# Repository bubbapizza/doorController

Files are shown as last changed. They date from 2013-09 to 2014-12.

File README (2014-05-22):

This is (going to be) a full DIY solution for a door controller.
The door can be locked or unlocked using an arduino or a raspberry pi
to interface witha Parallax serial RFID card reader for the controller
hardware.

The backend logic for the door controller is handled in python.  
The arduino sketches have no logic in them whatsoever.  All they do is 
accept single character commands over the virtual serial port 
and control some lights, a buzzer and rfid controller.  All back-end logic
is handled using python.

I've also included a couple Arduino sketches for dealing w/ Wiegand RFID 
card readers.  I'm not sure if the wiegand stuff actually works or not
since I never tested it.  One sketch is an RFID emulator which is 
supposed to emulate a wiegand card reader.  The other sketch is for 
controlling a door using a device that speaks the wiegand protocol.
testing

Shawn Wilson
Oct 29, 2013

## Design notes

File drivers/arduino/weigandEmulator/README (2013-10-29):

This sketch is for emulating a Wiegand RFID reader.  Upload this
sketch to an arduino, then you can type in RFID codes over the
serial port and it will send out the codes on pins 8 & 9 using the
Wiegand protocol.

NOTE: this has not been tested at all.  It may not work.

Shawn Wilson
Sept 11, 2013

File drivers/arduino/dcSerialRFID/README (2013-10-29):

This is an arduino sketch that acts as a simple door controller.
It reads RFID cards from a Parallax serial RFID card reader.  It also
controls two LEDs, a piezo buzzer and a relay to open the door.  

The controller has no logic in it whatsoever.  All it does is accept 
single character commands over the serial port which can be used
to control the lights, buzzers and rfid controller.  All logic should
be handled by external software.

Shawn Wilson
Sept. 13, 2013

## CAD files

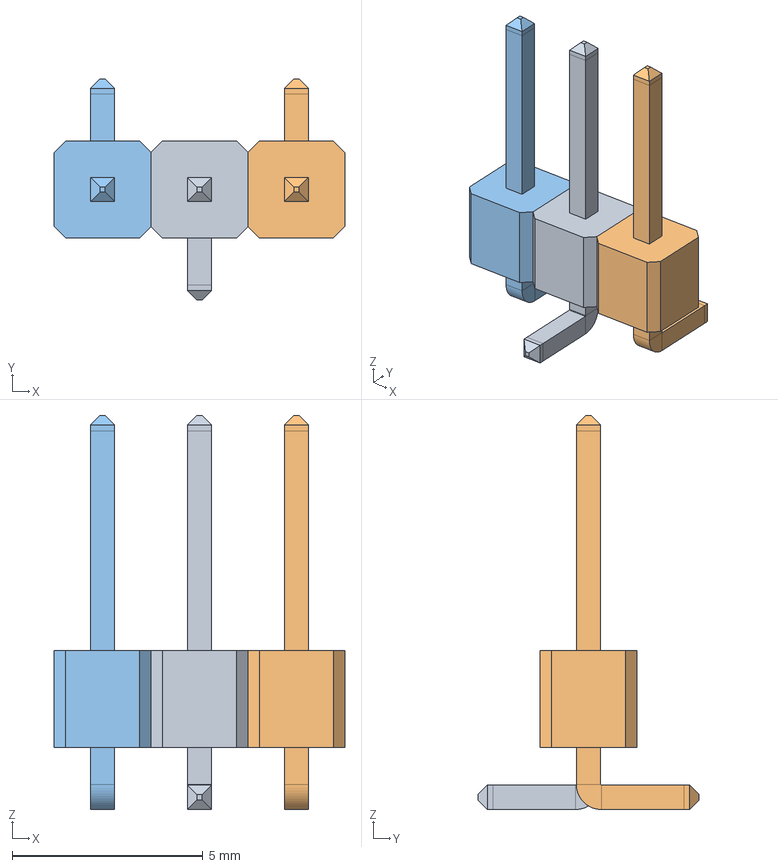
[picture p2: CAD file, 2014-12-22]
KiCAD/rpi-door-control/3D_models/SMD_Pins_x3.FCStd
7.62 x 5.80 x 10.3 mm
SMD Pin
SMD Pin (Mirror #1)
SMD Pin (Mirror #2)

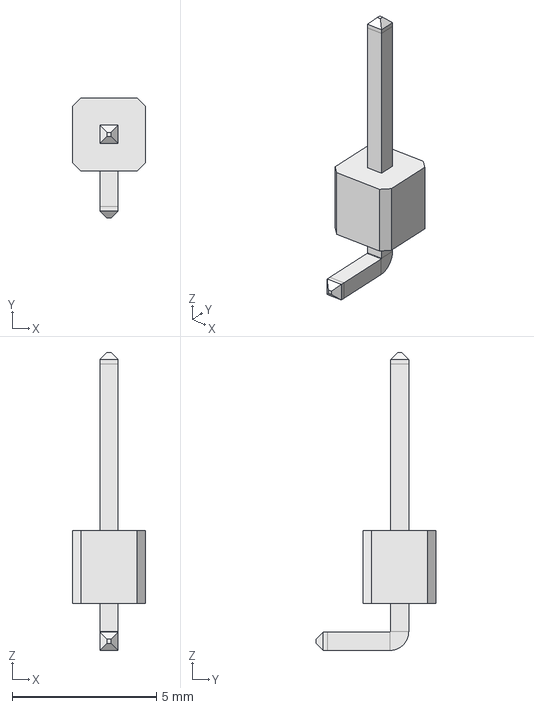
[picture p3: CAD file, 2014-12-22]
KiCAD/rpi-door-control/3D_models/SMD_Pin.FCStd
2.54 x 4.17 x 10.3 mm

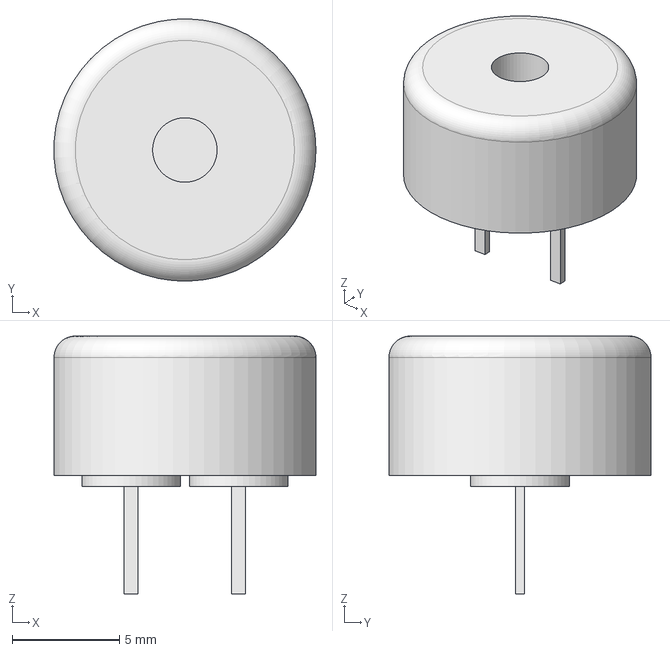
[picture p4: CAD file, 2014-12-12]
KiCAD/rpi-door-control/3D_models/TDK_buzzer.FCStd
12.2 x 12.2 x 12.0 mm

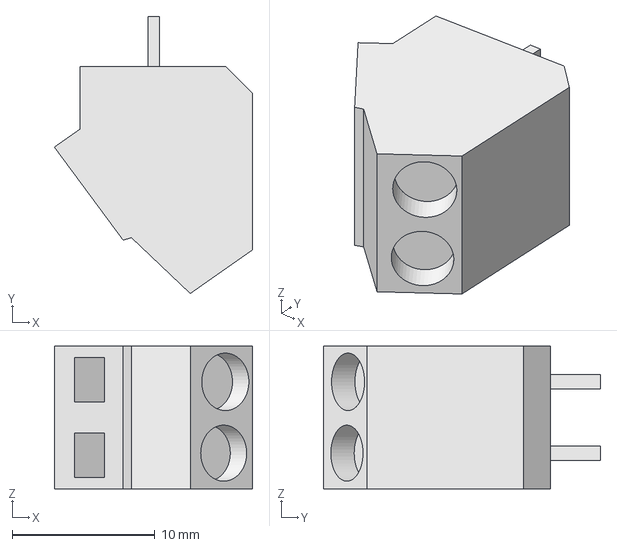
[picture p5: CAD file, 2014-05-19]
KiCAD/rpi-door-control/3D_models/kf103.FCStd
13.9 x 19.4 x 10.0 mm

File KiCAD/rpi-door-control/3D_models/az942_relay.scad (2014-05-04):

module pin134() {
	cube(size=[0.3, 1.0, 3.5], center=true);
};

module pin25() {
	cube(size=[0.3, 0.9, 3.5], center=true);
};

cube(size=[16.5, 22.5, 16.8]);
translate([(16.5 / 2), 2.1, (-3.5 / 2)]) rotate([0, 0, 90]) pin134();
translate([(16.5 / 2 - 6), 16.3, (-3.5 / 2)]) pin134();
translate([(16.5 / 2 + 6), 16.3, (-3.5 / 2)]) pin134();
translate([(16.5 / 2 + 6), 4.1, (-3.5 / 2)]) pin25();
translate([(16.5 / 2 - 6), 4.1, (-3.5 / 2)]) pin25();

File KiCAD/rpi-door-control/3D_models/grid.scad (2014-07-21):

/* This module creates grids. */

module grid(
   gridX, 
   gridY, 
   borderX, 
   borderY, 
   meshSolid,    // width of solid part of grid
   meshSpace,    // width of space part of grid
   thickness) {  // z height 

   /* Calculate the size of the dimensions of the meshed area. */
   meshX=gridX-(borderX*2);
   meshY=gridY-(borderY*2);

   echo (meshX,  meshY);

   /* Calculate the number of lines in the meshed area. */
   nX=floor(meshX/(meshSolid+meshSpace));
   nY=floor(meshY/(meshSolid+meshSpace));
   gridSize = meshSolid + meshSpace;
   echo (nX, nY, gridSize);


   intersection () {

      union() {
         /* 
          *  Draw the border box centered. 
          */
         difference() {
            cube (size=[gridX,gridY,thickness+ 2], center=true);
            cube (size=[meshX,meshY,thickness+ 2], center=true);
         } /* enddifference */
         
      
         /* 
          *  Draw the grid centered. 
          */
      
         /* Draw the lines parallel to y axis. */
         translate([-1 * (meshSolid / 2), 0, -1 * (thickness / 2)])
            union() {
               for (i = [0 : ceil(nX / 2)]) {
                  translate([i*(meshSolid+meshSpace), -1 * (gridY / 2), 0]) 
                     cube(size=[meshSolid, gridY, thickness]);
               } /* endfor */
               for (i = [0 : ceil(nX / 2)]) {
                  translate([-1 * i*(meshSolid+meshSpace), -1 * (gridY / 2), 0]) 
                     cube(size=[meshSolid, gridY, thickness]);
               } /* endfor */
            } /* endunion */
         
         /* Draw the lines parallel to the x axis. */
         translate([0, -1 * (meshSolid / 2), -1 * (thickness / 2)])
            union() {
               for (i = [0 : ceil(nY / 2)]) {
                  translate([-1 * (gridX / 2), i*(meshSolid+meshSpace), 0]) 
                     cube(size=[gridX, meshSolid, thickness]);
               } /* endfor */
               for (i = [0 : ceil(nY / 2)]) {
                  translate([-1 * (gridX / 2), -1 * i*(meshSolid+meshSpace), 0]) 
                     cube(size=[gridX, meshSolid, thickness]);
               } /* endfor */
            } /* endunion */
      } /* endunion */

      /* Slice off all the extra line widths on the edges. */
      cube (size=[gridX,gridY,thickness], center=true);

   } /* endintersection */

} /* endmodule */


grid(21, 41, 0, 0, 2, 8, 5);
   

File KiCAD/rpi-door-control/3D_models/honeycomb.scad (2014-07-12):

/* The honeycomb module draws a rectangle filled with honecombs like
   http://www.thingiverse.com/thing:321880 
   This code was taken from Peter O on the openscad forums. 
*/

module hc_hexagon(size, height) {
   box_width = size/1.75;
   for (r = [-60, 0, 60]) 
      rotate([0,0,r]) cube([box_width, size, height], true);
} /* endmodule */

module hc_column(length, height, cell_size, wall_thickness) {
   no_of_cells = floor(1 + length / (cell_size + wall_thickness)) ;
   for (i = [0 : no_of_cells]) {
      translate([0,(i * (cell_size + wall_thickness)),0])
         hc_hexagon(cell_size, height + 1);
   } /* endfor */
} /* endmodule */

module honeycomb (length, width, height, cell_size, wall_thickness) {
   no_of_rows = floor(1.75 * length / (cell_size + wall_thickness)) ;
   tr_mod = cell_size + wall_thickness;
   tr_x = sqrt(3)/2 * tr_mod;
   tr_y = tr_mod / 2;
   off_x = -1 * wall_thickness / 2;outer_walls   = 10;
   off_y = wall_thickness / 2;outer_walls   = 10;

   difference() { 
      cube([length, width, height]);
      for (i = [0 : no_of_rows]) {
         translate([i * tr_x + off_x, (i % 2) * tr_y + off_y, (height) / 2])
            hc_column(width, height, cell_size, wall_thickness);
      } /* endfor */
   } /* enddifference */
} /* endmodule */ 


/* Draw a sample honeycomb grid. */
honeycomb(80, 80, 5, 5, 1); 

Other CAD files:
KiCAD/rpi-door-control/3D_models/pcb_milling_jig_bottom.scad
KiCAD/rpi-door-control/3D_models/pcb_milling_jig_middle.scad
KiCAD/rpi-door-control/3D_models/pcb_milling_jig_mount_block.scad
KiCAD/rpi-door-control/3D_models/pcb_milling_jig_top.scad

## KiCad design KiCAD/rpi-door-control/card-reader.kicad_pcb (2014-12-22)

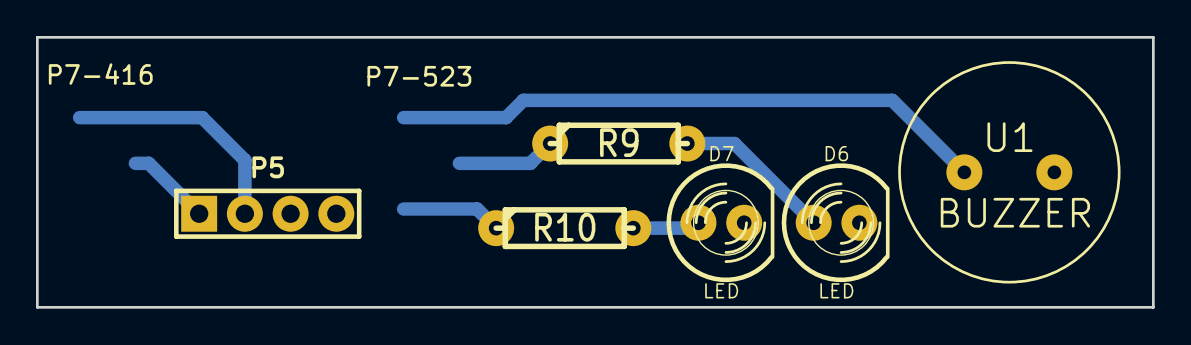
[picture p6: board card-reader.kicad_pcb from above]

Board: 2 copper layers, 62.0 x 15.0 mm, 7 parts (0 on the bottom side), 8 nets.

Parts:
D6: LED; LED-5MM-RED
D7: LED; LED-5MM
P5: CONN_4; PIN_ARRAY_4x1_RIGHT_ANGLE
P7-416: CONN_6; PINS_3x2_WIDE_SMD
R9, R10: 330; R3-LARGE_PADS
U1: BUZZER; BUZZER_SMALL

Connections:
+5V: P5.1, P7-416.1
/BELL: P7-416.5, U1.1
/GREEN: P7-416.3, R10.1
/RED: P7-416.2, R9.1
/RFID TXD: P5.2, P7-416.4
GND: D6.2, D7.2, P5.3, P5.4, P7-416.6, U1.2
unnamed: D7.1, R10.2
unnamed: D6.1, R9.2

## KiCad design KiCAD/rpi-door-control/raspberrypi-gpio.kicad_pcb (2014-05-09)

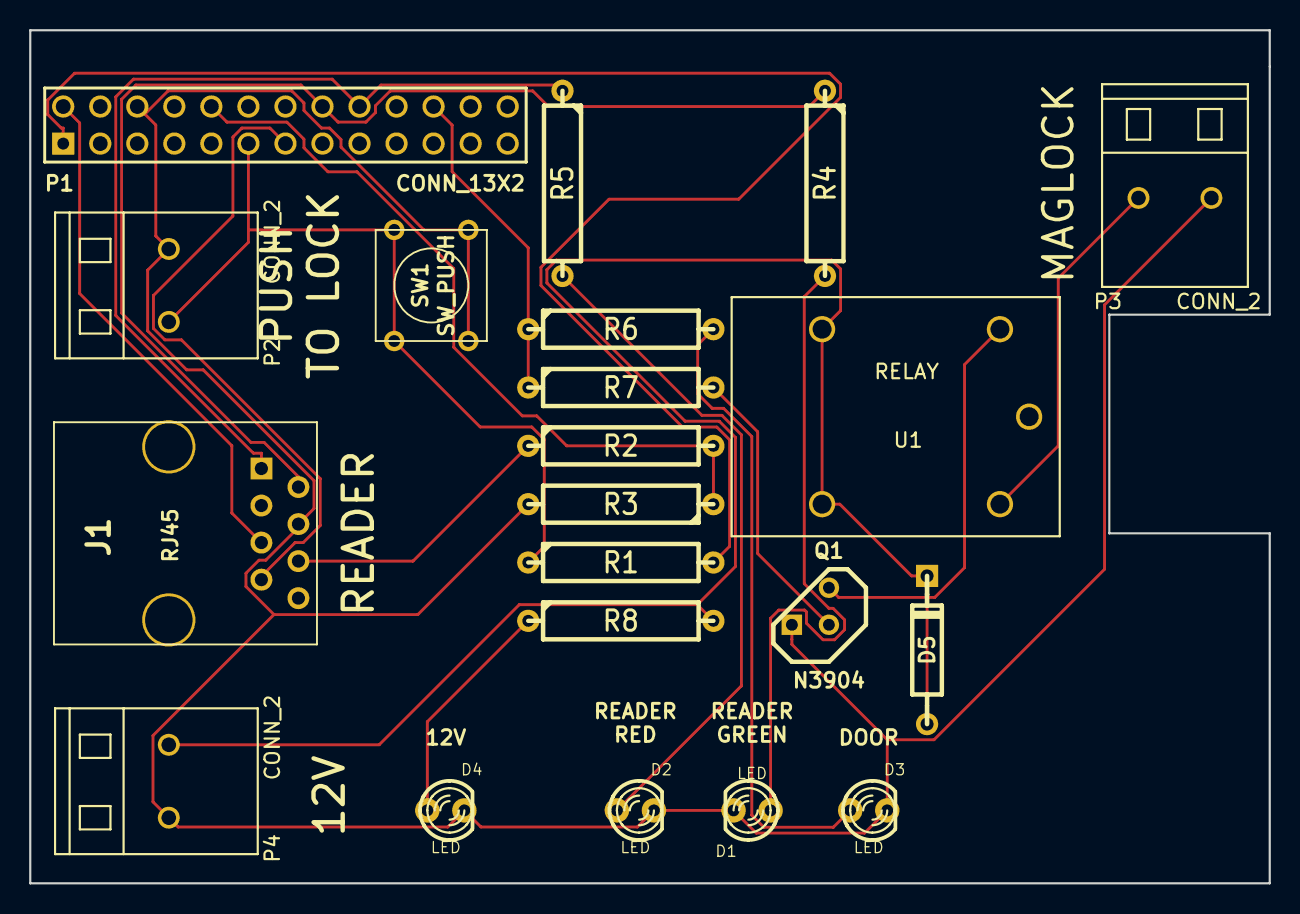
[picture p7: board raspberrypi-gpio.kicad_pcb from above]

Board: 2 copper layers, 85.0 x 58.5 mm, 21 parts (0 on the bottom side), 18 nets.

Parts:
D1, D2, D3, D4: LED; LED-3MM
D5: 1N4007; DO-41
J1: RJ45; RJ45_8
P1: CONN_13X2; pin_array_13x2
P2, P3, P4: CONN_2; C2_KF103
Q1: N3904; TO92
R1: 10K; R5
R2: 1.8K; R5
R3: 3.3K; R5
R4, R5, R6: 330; R5
R7: 1K; R5
R8: 2K; R5
SW1: SW_PUSH; SW_PUSH_SMALL
U1: RELAY; RELAY_AZ942

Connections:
+3.3V: P1.1, R1.2
+5V: J1.5, P1.2
+12V: D5.2, P4.2, R8.2, U1.3, U1.4
/BELL: J1.7, P1.13
/GPIO17: P1.11, P2.1, R1.1, SW1.1
/GPIO23: J1.2, P1.16, R4.1
/GPIO24: J1.1, P1.18, R5.1
/GPIO25: P1.22, R6.1, R7.1
/RFID TXD: J1.6, R2.1
/RXD: P1.10, R2.2, R3.1
GND: D1.2, D2.2, D3.2, D4.2, J1.4, P1.6, P2.2, P3.2, P4.1, Q1.1, R3.2, SW1.2
unnamed: P3.1, U1.2
unnamed: Q1.2, R7.2
unnamed: D5.1, Q1.3, U1.5
unnamed: D1.1, R4.2
unnamed: D2.1, R5.2
unnamed: D3.1, R6.2
unnamed: D4.1, R8.1

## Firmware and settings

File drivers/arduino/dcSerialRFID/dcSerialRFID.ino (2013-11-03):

/************
 *
 *        Copyright (C) 2013 Shawn Wilson
 *        shawn@ch2a.ca
 *        
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
 *
 * 
 *  This program is a simple rfid door controller.  It provides a serial 
 *  interface for reading RFID cards and controlling a magnetic door lock,
 *  a green led, a red led and a piezo buzzer.
 *
 *  ChangeLog
 *  0.3
 *    - Added commands for querying the states of individual subdevices.
 * 
 *************/

#include <SoftwareSerial.h>


/**** CONSTANTS ****/

#define VERSION 0.3

/* Set serial communications rates. */
#define BITRATE_SERIAL_COMMANDS 115200
#define BITRATE_RFID_READER 2400

/* Set up pins for lights, buzzer(s), door lock, and RFID enable. */
#define GREEN_LED_PIN 4
#define RED_LED_PIN 5
#define BELL_PIN 6
#define DOOR_LOCK_PIN 7
#define RFID_ENABLE_PIN 2

/* The Parallax RFID reader is a read-only device, but we still have
   to set up two pins for the software serial driver.  The SOUT pin
   of the Parallax reader gets connected to the Rx pin and the 
   Tx pin is unused. */
#define RFID_RX_PIN 8
#define RFID_TX_PIN 9

/* When the RFID reader detects a card, it sends 12 bytes over the 
   serial line.  The first byte is 0x0A and the last byte is 0x0A. 
   Here, we just set up some constants for those values. */
#define RFID_NUM_BYTES 10
#define RFID_START_BYTE 10
#define RFID_STOP_BYTE 13

/* Set the piezo buzzer frequency and duration. */
#define BELL_FREQUENCY 261  // middle C
#define BELL_DURATION 500  // milliseconds

/* Set up commands triggered by incoming characters over serial. */
#define CMD_DOOR_UNLOCK 'd'
#define CMD_DOOR_LOCK 'D'
#define CMD_GREEN_OFF 'g'
#define CMD_GREEN_ON 'G'
#define CMD_RED_OFF 'r'
#define CMD_RED_ON 'R'
#define CMD_BELL 'b'
#define CMD_RFID_DISABLE 'f'
#define CMD_RFID_ENABLE 'F'
#define CMD_STATUS_ALL 's'
#define CMD_STATUS_RED '1'
#define CMD_STATUS_GREEN '2'
#define CMD_STATUS_DOOR '3'
#define CMD_STATUS_RFID '4'


/* Set up message strings to be sent back over serial. */
#define MSG_LOCK "DOOR LOCKED"
#define MSG_UNLOCK "DOOR UNLOCKED"
#define MSG_GREEN_OFF "GREEN LED OFF"
#define MSG_GREEN_ON "GREEN LED ON"
#define MSG_RED_OFF "RED LED OFF"
#define MSG_RED_ON "RED LED ON"
#define MSG_BELL "BELL RING"
#define MSG_RFID_ENABLED "RFID READER ENABLED"
#define MSG_RFID_DISABLED "RFID READER DISABLED"
#define MSG_STATUS_HEADER "===== Door Controller Status ======"
#define MSG_STATUS_FOOTER "==================================="


/**** GLOBAL VARIABLES *****/

SoftwareSerial rfidReader(RFID_RX_PIN, RFID_TX_PIN);
char cmdChr;
char rfidChr;
String rfidCode = "";
boolean buildCode = false;



/**********
 *  Print out the status of any one door controller subdevice or print
 *  out the state of all subdevices.
 **********/
void printStatus(char cmd) {
   /*
    *  HEADER
    */
   if (cmd == CMD_STATUS_ALL) {
      Serial.println(MSG_STATUS_HEADER);
      Serial.print("VERSION ");
      Serial.println(VERSION);
   } /* endif */


   /* Get RFID reader status. */
   if (cmd == CMD_STATUS_ALL || cmd == CMD_STATUS_RFID) {
      if (!digitalRead(RFID_ENABLE_PIN)) {
         Serial.println(MSG_RFID_ENABLED);
      } else {
         Serial.println(MSG_RFID_DISABLED);
      } /* endif */
   } /* endif */

   /* Get door status. */
   if (cmd == CMD_STATUS_ALL || cmd == CMD_STATUS_DOOR) {
      if (digitalRead(DOOR_LOCK_PIN)) {
         Serial.println(MSG_LOCK);
      } else {
         Serial.println(MSG_UNLOCK);
      } /* endif */
   } /* endif */

   /* Get green LED status. */
   if (cmd == CMD_STATUS_ALL || cmd == CMD_STATUS_GREEN) {
      if (digitalRead(GREEN_LED_PIN)) {
         Serial.println(MSG_GREEN_ON);
      } else {
         Serial.println(MSG_GREEN_OFF);
      } /* endif */
   } /* endif */

   /* Get red LED status. */
   if (cmd == CMD_STATUS_ALL || cmd == CMD_STATUS_RED) {
      if (digitalRead(RED_LED_PIN)) {
         Serial.println(MSG_RED_ON);
      } else {
         Serial.println(MSG_RED_OFF);
      } /* endif */
   } /* endif */


   /*
    *  FOOTER
    */
   if (cmd == CMD_STATUS_ALL) {
      Serial.println(MSG_STATUS_FOOTER);
   } /* endif */
} /* endfunction */



/**********
 *  INIT ROUTINE
 **********/
void setup() {

   /* Initialize communications. */
   Serial.begin(BITRATE_SERIAL_COMMANDS);
   rfidReader.begin(BITRATE_RFID_READER);

   /* Initialize pins. */
   pinMode(GREEN_LED_PIN, OUTPUT);  
   pinMode(RED_LED_PIN, OUTPUT);  
   pinMode(BELL_PIN, OUTPUT);  
   pinMode(DOOR_LOCK_PIN, OUTPUT);  
   pinMode(RFID_ENABLE_PIN, OUTPUT);  

   /* Start listening for RFID tags, lock the door and turn on 
      the red LED. */
   lockDoor();
   enableRFID();
   digitalWrite(RED_LED_PIN, HIGH);

   Serial.print("\nDoor controller ver. ");
   Serial.print(VERSION);
   Serial.println(" initialized.");
} /* endfunction */



/**********
 *  EVENT LOOP
 **********/
void loop() {

   /***** READ RFID CARD *****/

   if (rfidReader.available()) {

      /* Keep reading till we run out of bytes. */
      while (rfidReader.available()) {
         rfidChr = rfidReader.read();

         /* If we got a start byte, then start storing the code. */
         if (rfidChr == RFID_START_BYTE) {
            buildCode = true;
            rfidCode = "";
         
         /* If we got a stop byte, then make sure we have enough
            characters to build a code.  Otherwise, we have junk. */
         } else if (rfidChr == RFID_STOP_BYTE) {

            if ((buildCode == true) && 
                (rfidCode.length() == RFID_NUM_BYTES)) {
               Serial.print("CARD ");
               Serial.println(rfidCode);
            } /* endif */

            buildCode = false;
            rfidCode = "";

         /* We got a regular character so build the code. */
         } else if (buildCode == true) {

            /* Check to make sure we still have a valid code. */
            if (rfidCode.length() < RFID_NUM_BYTES) {
               rfidCode += rfidChr;

            /* The code is too long, we have garbage somewhere. */
            } else {
               buildCode = false;
               rfidCode = "";
            } /* endif */
         } /* endif */

      } /* endwhile */
   } /* endif */
            


   /****** READ SERIAL COMMANDS *****/ 

   if (Serial.available() > 0) {
         
         cmdChr = Serial.read();

         /* 
          *  Execute any one-character commands that came in on the
          *  serial port.
          */

         /*** Unlock door. ***/
         if (cmdChr == CMD_DOOR_UNLOCK) {
            digitalWrite(DOOR_LOCK_PIN, LOW);
            Serial.println(MSG_UNLOCK);

         /*** Lock door. ***/
         } else if (cmdChr == CMD_DOOR_LOCK) {
            digitalWrite(DOOR_LOCK_PIN, HIGH);
            Serial.println(MSG_LOCK);

         /*** Turn on green LED. ***/
         } else if (cmdChr == CMD_GREEN_ON) {
            digitalWrite(GREEN_LED_PIN, HIGH);
            Serial.println(MSG_GREEN_ON);

         /*** Turn off green LED. ***/
         } else if (cmdChr == CMD_GREEN_OFF) {
            digitalWrite(GREEN_LED_PIN, LOW);
            Serial.println(MSG_GREEN_OFF);

         /*** Turn on red LED. ***/
         } else if (cmdChr == CMD_RED_ON) {
            digitalWrite(RED_LED_PIN, HIGH);
            Serial.println(MSG_RED_ON);

         /*** Turn off red LED. ***/
         } else if (cmdChr == CMD_RED_OFF) {
            digitalWrite(RED_LED_PIN, LOW);
            Serial.println(MSG_RED_OFF);

         /*** Enable RFID reader. ***/
         } else if (cmdChr == CMD_RFID_ENABLE) {
            digitalWrite(RFID_ENABLE_PIN, LOW);
            Serial.println(MSG_RFID_ENABLED);

         /*** Disable RFID reader. ***/
         } else if (cmdChr == CMD_RFID_DISABLE) {
            digitalWrite(RFID_ENABLE_PIN, HIGH);
            Serial.println(MSG_RFID_DISABLED);

         /*** Ring bell. ***/
         } else if (cmdChr == CMD_BELL) {
            tone(BELL_PIN, BELL_FREQUENCY, BELL_DURATION);
            Serial.println(MSG_BELL);

         /*** STATUS CODES ***/
         } else if (cmdChr == CMD_STATUS_ALL) {
            printStatus(CMD_STATUS_ALL);
         } else if (cmdChr == CMD_STATUS_RED) {
            printStatus(CMD_STATUS_RED);
         } else if (cmdChr == CMD_STATUS_GREEN) {
            printStatus(CMD_STATUS_GREEN);
         } else if (cmdChr == CMD_STATUS_DOOR) {
            printStatusCMD_STATUS_DOOR);
         } else if (cmdChr == CMD_STATUS_RFID) {
            printStatus(CMD_STATUS_RFID);
         } /* endif */
   } /* endif */

} /* endfunction */

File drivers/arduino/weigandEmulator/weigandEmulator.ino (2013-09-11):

/*****************************
 *  This program emulates a Wiegand RFID device.  This code is
 *  modified from an HID ProxPoint Skimmer written by Brad Antoniewicz.
 *  I just pulled out the code that taked data received from the serial
 *  interface on the Arduino (in binary) and sends the data out using
 *  the Wiegand protocol.
 *
 * Arduino Pinouts:
 *        8 - Wiegand output Data 0 (Green)
 *        9 - Wiegand output Data 1 (White)
 *
 * 26-Bit Wiegant Format: 
 * Bit 1 = Even Parity over Bits 2 - 13
 * Bits 2 - 9 = Facility Code (0 to 255) Bit 2 is MSB
 * Bits 10 - 25 = ID Number (0 to 65,535) Bit 10 is MSB
 * Bits 26 Odd parity over bits 14 to 25
 *
 *  Shawn Wilson
 *  Sept. 11, 2013
 *****************************/

/* CONSTANTS */
#define CARD_LEN 26
#define LED 13   // output LED
#define WIEGAND_D0 8  // output DATA0 (Green) to Controller
#define WIEGAND_D1 9  // output DATA1 (White) to Controller
#define DELAY_BIT_SIGNAL 1000  //signal delay in microseconds
#define DELAY_BIT_SPACING 10000  //signal delay in microseconds

/* VARIABLES */ 
unsigned long cardValue = 0;
int incomingByte = 0; 
int sInputCount = 0;


/******
 * Reset serial port to ready state.
 ******/
void resetState() {
   Serial.println("[+] Reseting State...");
   delay(10);
   Serial.flush();
   sInputCount=0;
} /* endfunction */


/******
 * Write a card value using Wiegand protocol.
 ******/
void writeCard(volatile unsigned long sendValue) {

    short x;

    Serial.println("[-] Sending Data:");
    Serial.print("\t");

    /*
     *  Loop through each bit of the send value and send bits 
     *  one at a time. 
     */
    for (x = CARD_LEN; x >= 0; x--) {

      /** 1 **/
      if (bitRead(sendValue, x) == 1) {
        Serial.print("1"); 
        digitalWrite(WIEGAND_D1, LOW);
        delayMicroseconds(DELAY_BIT_SIGNAL);
        digitalWrite(WIEGAND_D1, HIGH);

      /** 0 **/
      } else if (bitRead(sendValue, x) == 0) {
        Serial.print("0");
        digitalWrite(WIEGAND_D0, LOW);
        delayMicroseconds(DELAY_BIT_SIGNAL);
        digitalWrite(WIEGAND_D0, HIGH);
      } /* endif */

      delayMicroseconds(DELAY_BIT_SPACING);
    } /* endfor */

    Serial.println();
} /* endfunction */



/******
 *  Build the card value one from '0' and '1' characters.
 ******/
void processInput(int byte) {
   if (byte == 49) { // DECIMAL 1 
      sInputCount++; 
      bitSet(cardValue, CARD_LEN - sInputCount);

   } else if (byte == 48) { // DECIMAL 0
      sInputCount++; 
      bitClear(cardValue, CARD_LEN - sInputCount);

   } else {
       Serial.print("[!] Recieved invalid Value:");
       Serial.println(byte);
       resetState();
   } /* endif */
} /* endfunction */


/******
 *  Decode a card value and print the details of it.
 ******/
void printCardData(unsigned long data) {
   int serialNumber = (data >> 1) & 0x3fff;
   int siteCode = (data >> 17) & 0x3ff;

   Serial.print("\tHEX: ");
   Serial.print(data,HEX);
   Serial.print(" SITE: ");
   Serial.print(siteCode);
   Serial.print(" CODE: ");
   Serial.println(serialNumber);
   Serial.print("\tBINARY: ");
   Serial.println(data, BIN);
} /* endfunction */


/********
 *  INITIAL STARTUP
 ********/
void setup() {

  /* Initialize the protocol pins. */
  pinMode(WIEGAND_D0, OUTPUT);
  pinMode(WIEGAND_D1, OUTPUT);

  /* When both pins are high, it means no data. */
  digitalWrite(WIEGAND_D0, HIGH);
  digitalWrite(WIEGAND_D1, HIGH);
  
  sInputCount = 0; 
  Serial.begin(9600);
  Serial.println("Please provide a tag value");
  Serial.println("For Binary input, it must be 26 bits long");
  Serial.println("No parity needs, just add two 0's to the beginning");
  Serial.println("e.g. 00001001100011111110010101");
}


/******
 *  MAIN LOOP
 ******/
void loop() {
  
   /* 
    *  Accept input via the serial interface. 
    */
   if (Serial.available() > 0 ) {
     
      /* Read in one byte and print a dot if a character is received. */
      incomingByte = Serial.read();
      Serial.print(".");
      delay(10);
  
      processInput(incomingByte);
      if ((sInputCount > 0) && (sInputCount != CARD_LEN) && 
          (Serial.peek() == -1)) {
 
         Serial.println("\n[!] Invalid Input Length!");
         resetState();
      } /* endif */
   } /* endif */


   /* If we got the right number of card digits, send the value. */
   if (sInputCount == CARD_LEN) {
      Serial.println("");
      Serial.println("[-] Sending current Serial Buffer");
      writeCard(cardValue); 
      printCardData(cardValue);
      resetState();


   } else if (sInputCount > CARD_LEN) {
      Serial.println("[!] Sorry, looks like your input was too long.. ");
      resetState();
   } /* endif */
          
} /* endfunction */

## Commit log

2013-09-14 Renamed ino file because arduino IDE doesn't like dashes in sketch names
2013-10-11 Renamed door controller sketch because latest versions of Arduino IDE crash on projects with dashes in the name.
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2013-10-14 First crack at the arduino driver
    [arduino.py]
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2013-11-03 dummy driver has been replaced by base.py
    [base.py]
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2013-11-03 Rewrote arduino to use base classes. Needs debugging. Also did some bug fixing in base, rpi and status
    [arduino.py, base.py, rpi.py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]
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2014-03-09 Added KiCAD project for RPi door controller shield
    [raspberrypi-gpio.kicad_pcb, raspberrypi-gpio.sch]
2014-03-14 redrew schematic to make it follow more standard conventions
    [card-reader.sch, raspberrypi-gpio.sch]
2014-03-20 Make multi-sheet and fix stuff
    [card-reader.sch, raspberrypi-gpio.sch]
2014-04-26 Added datasheets, start footprint designs
    Merged in changes from svn repo
    [card-reader.sch, raspberrypi-gpio.kicad_pcb, raspberrypi-gpio.sch]
2014-04-26 Added terminal block footprint and initial layout of board connectors
    [raspberrypi-gpio.kicad_pcb]
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2014-05-03 components placed - who knows if the layout is any good or not
    [raspberrypi-gpio.kicad_pcb]
2014-05-04 Added autorouter files and generated single layer routes
    [raspberrypi-gpio.dsn, raspberrypi-gpio.kicad_pcb]
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2014-05-04 Fixed colors on 3D relay model
2014-05-06 added rj45 datasheet that matches the built-in kicad footprint
    [raspberrypi-gpio.dsn]
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2014-05-09 Start of v0.5 of schematic. Converted the circuit to isolate 12V with an opto-isolator. Will redraw the PCB to be just a bullshit square linked by a ribbon cable or something so it can be milled with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
    [card-reader.sch, raspberrypi-gpio.dsn, raspberrypi-gpio.kicad_pcb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]
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2014-05-16 12V circuit is done but man the data side is tricky
    [ss-circuit-mill.kicad_pcb]
2014-05-16 Missed a track on the power side
    [ss-circuit-mill.kicad_pcb]
2014-05-17 drew up single sided board but can't connect grounds. Needs serious rerouting
    [card-reader.sch, raspberrypi-gpio.sch, ss-circuit-mill.kicad_pcb]
2014-05-17 Got parts traces done miraculously, just have to optimize placement now
    [ss-circuit-mill.kicad_pcb]
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2014-05-17 Very close to the final layout. Just have to reposition LEDs, put some labels, and make some 3D models.
    [ss-circuit-mill.kicad_pcb]
2014-05-18 Clean up single sided pcb, change version numbers
    [raspberrypi-gpio.sch, ss-circuit-mill.kicad_pcb]
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2014-05-18 Added silk screen text, drill holes, general polishing
    [single-sided-DIY.kicad_pcb]
2014-05-18 Start 3D model of terminal block, renamed relay file
    [KF-103_2pole_terminal_block.scad, az942_relay.scad]
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2014-05-20 Got 3D model for terminal blocks working. Still need to change the colour of the skin but they do show up in the KiCAD 3D view.
    [single-sided-DIY.kicad_pcb]
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2014-05-22 Swapped R8 and R11, maximized copper ground area for +12V and added a red LED to the custom footprints.
    [single-sided-DIY.kicad_pcb]
2014-05-22 Changed the RED, DOOR and +12V LEDs to red
    [single-sided-DIY.kicad_pcb]
2014-05-22 Moved parts around on 12V side and aligned holes better
    [card-reader.sch, raspberrypi-gpio.sch, single-sided-DIY.kicad_pcb]
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2014-05-29 created gerber file, generated g-code with FlatCAM and created an openSCAM project to simulate cutting a board.
    [single-sided-DIY.kicad_pcb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]
2014-06-14 Changed mounting holes to Non-plated through-hole, changed the origin for generating gerbers. Also added some alignment holes but I have no idea where those are used.
    [single-sided-DIY.kicad_pcb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]
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2014-07-09 Changed the offset of where gcode is generated from, added the gcode files for each drill size.
    [single-sided-DIY.kicad_pcb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]
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2014-07-13 Base of jig looks ok. May want to add a mesh.
    [pcb_milling_jig.scad]
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2014-07-15 Beefed up jig border, added holes for 4mm nuts, bumped up screw hole sizes a bit
    [pcb_milling_jig_bottom.scad, pcb_milling_jig_top.scad]
2014-07-15 Changed nuts to 4mm and added grid to bottom jig
    [pcb_milling_jig_bottom.scad]
2014-07-16 Changed dimensions a bit to account for measured screw size
    [pcb_milling_jig_bottom.scad]
2014-07-21 Improved Grid module so grids are centered now.
    [grid.scad]
2014-07-21 Fixed some grid issues w/ borders
    [grid.scad]
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2014-07-21 Rewrote how the grid method is used. jig is now more parametric.
    [pcb_milling_jig_bottom.scad]
2014-07-21 Bottom jig now has a bit of a pocket to pad with cardboard/styrofoam/balsa wood, etc. for sacrificial cutting.
    [pcb_milling_jig_bottom.scad]
2014-07-21 Added a screw test and it looks like something changed w/ the gerbers too
    [pcb_milling_jig_screw_test.scad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]
2014-07-22 Added a pocket on the bottom since the t-nuts protrude a little bit above the bed
    [pcb_milling_jig_bottom.scad]
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2014-07-23 Got rid of t-nut pockets, slimmed things down for the bottom jig
    [pcb_milling_jig_bottom.scad]
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2014-07-25 renamed the test file to be the actual mounting block
    [pcb_milling_jig_mount_block.scad]
2014-07-28 Added drill holes for the pcb milling jig
    [single-sided-DIY.kicad_pcb]
2014-08-06 Mirrored the y axis and changed the zero point to pin 1 of the rj45 connector. Exported new gcode for 0.9mm drill.
    [single-sided-DIY.kicad_pcb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]
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2014-12-06 Added buzzer footprint and datasheet, started the RRGB board for the door swiper
    [RRGB_board.kicad_pcb]
2014-12-10 Working on the card reader RRGB board. Changed RRGB board over to card-reader project to match schema
    [RRGB_board.kicad_pcb, card-reader.kicad_pcb, card-reader.sch]
2014-12-12 Added 3d model for TDK buzzer
    [TDK_buzzer.FCStd, card-reader.kicad_pcb]
2014-12-13 Changed cardreader schematic to allow for converting from rj45 to a 6 pin connector of some sort. Makes things easier for the cardreader board.
    [card-reader.sch, raspberrypi-gpio.sch]
2014-12-13 cardreader board almost done, just need stupid buzzer to get connected in ratsnest
    [card-reader.kicad_pcb, card-reader.sch]
2014-12-14 board looks ok now, just need to fix bare_wire footprint
    [card-reader.kicad_pcb]
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2014-12-19 Tweaked footprints for smd header pins on card reader
    [card-reader.kicad_pcb]
2014-12-19 Tagged wrong version of card reader. Should be ver 0.4.1
    [card-reader.kicad_pcb]
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2014-12-22 Added the 6 pins header 3D model to the card reader pcb, fattened up the SMD pin pads to 2mm wide
    [SMD_Pins_x3.FCStd, card-reader.kicad_pcb]
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2014-12-25 Fixed the backwards transistors and the upside down relay on the door controller pcb
    [single-sided-DIY.kicad_pcb]

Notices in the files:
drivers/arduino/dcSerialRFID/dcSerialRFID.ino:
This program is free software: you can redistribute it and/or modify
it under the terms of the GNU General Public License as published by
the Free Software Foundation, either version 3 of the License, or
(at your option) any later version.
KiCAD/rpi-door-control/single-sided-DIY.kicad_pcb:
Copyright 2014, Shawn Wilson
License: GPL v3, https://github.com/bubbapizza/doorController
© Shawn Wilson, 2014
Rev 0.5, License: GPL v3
